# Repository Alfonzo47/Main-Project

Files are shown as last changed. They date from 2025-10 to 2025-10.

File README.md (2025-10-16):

# Main-Project

# Project Ironman

This project focoses on developing a small prototype of an isokinetic dynamometer specifically designed for a single finger joint to facilitate the collection of relevant data 
and validate the practical functionality of the design. The idea of our device is to measure muscle strength under a constant angular velocity or extension. The core goal of this
prototype is to strip down the functionality of the original, full-scale clinical isokinetic dynamometer to just a few essential components. This makes the device significantly 
cheaper and easier to implement in various smaller clinics or hospitals. Our intended user is primarily physiotherapists and researchers who require the data for the 
rehabilitation of patients with joint related injuries. Our project aims to widen the access to this type of machine.

# Components we used
- Steppermoter: Nema17
- Oled-Screen: 0.96 tum, I20
- Amplifyer: HX711
- Loadcell
- Driver: A4988
- Arduino microcontroller: r4 wifi
- Micro SD card
- Magnetic Encoder: AS5600

# Technical Approach

The system's core consists of an Arduino microcontroller integrated with an AS5600 magnetic encoder. The control logic is developed using the C language, ensuring quick execution 
for real-time control and analysis. The physical motion simulates finger flexion/extension using a specially 3D designed gear-driven system. A Load Cell is mounted on one of the 
gears, acting as the axis where the user's finger applies force during the simulated extesion.

The key to achieving Isokinetic Control is:
- Encoder Measurement: The AS5600 encoder continuously measures the angular position of the moter shaft.
- Software: It combines all the working components as well as documenting all the data in real time. Furthermore the software saves all the data, showing applied force at a
certain angle.  
- Data Collection: Simultaneously, the Load Cell accurately measures the applied force and the magnetic encoder helps to show at what angle the motor is in the rotation.

Both angle and weight values are updated and displayed in real time, while the code continuously drives the motor. The data is showed both on the OLED-screen during the trail and on a computer after the trail, making it possible to analyze and plot.

# User Interaction

The user interacts with the prototype through a simple and intuitive setup. The user places their finger on the load cell axis, where the mechanical system simulates controlled
finger extension. The prototype is supose to mimic the basic functionality of the real isokinetic dynamometer so during the trail the user experiences some recistance while 
extending the finger with the loadcell. During this process, the data from the loadcell and the magnetic encoder is transmitted to the software and visualized through a C-based interface and provides real-time readings of the angle and applied force during the test. The user experience is designed to be straightforward, allowing for easy setup and clear
feedback without the complexity of a full clinical device.

# Start up the Arduino-system

https://curiousscientist.tech/blog/as5600-magnetic-position-encoder

# Designs 





The figure shows a geardesign to combine the motor to the loadcell





The figure shows a piece to combine the magnetic encoder and the motor 





caseSketch

The figure shows the intended design for the prototype. This model offers the user to rest the palm while doing the test. The cylindrical shape in the design represents one of the gears



The figure shows the schematic for the electrical circuit made in KiCad





The figures shows the KiCad circuit on a PCB board and a 3D design of the PCB board to print for later use

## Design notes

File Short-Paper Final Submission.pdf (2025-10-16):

# Ironman

T.Thorisson, T.C.Linusson, S.Öberg. L.Birk. B.Chen

# Abstract

Isokinetic dynamometers are essential tools for measuring muscle strength, but their high cost and large size limit their use. By creating a more simplified and affordable version, accessibility will increase for clinics, leading to more data for researchers and improved patient rehabilitation.

# 1.1 Introduction

Isokinetic dynamometers are valuable tools in healthcare and sports medicine because they provide detailed information about dynamic muscle contractions [1]. However, commercial systems are typically large, expensive, and require professional operation, making them difficult to implement in smaller clinics or hospitals [2,3].

Traditional methods like manual and isometric testing cannot accurately capture strength changes during eccentric contractions or across full joint ranges of motion but isokinetic dynamometers address these issues [4]. However by simplifying the design, focusing only on angle and torque measurements, using compact components, a low-cost, motor-driven dynamometer with sensors and 3D modeling support could significantly reduce cost and size, making it more accessible for wider clinical use.

# 2.1 Design

A small-scale prototype of an isokinetic dynamometer used on the finger was constructed to facilitate the collection of relevant data and validate the practical functionality of the design. The system's motor is operated by a microcontroller (MCU) that uses sensors to control its operation via force and angle from an index finger extension.

### 2.2 Case Design

The prototype case was designed to house and protect the internal components of the isokinetic dynamometer, while ensuring ergonomic interaction for the user, consisting of three main sections, space for the motor, sensors and MCU. The upper section accommodates the motor and its attached gear as well as a magnetic sensor that’s attached to the motor. Below is additional space for a bottom gear where the load cell is attached to, forming an axis on which the user’s finger applies force to. Then there is more space in the section where the user’s palm will rest that contains most of the MCU and circuitry.

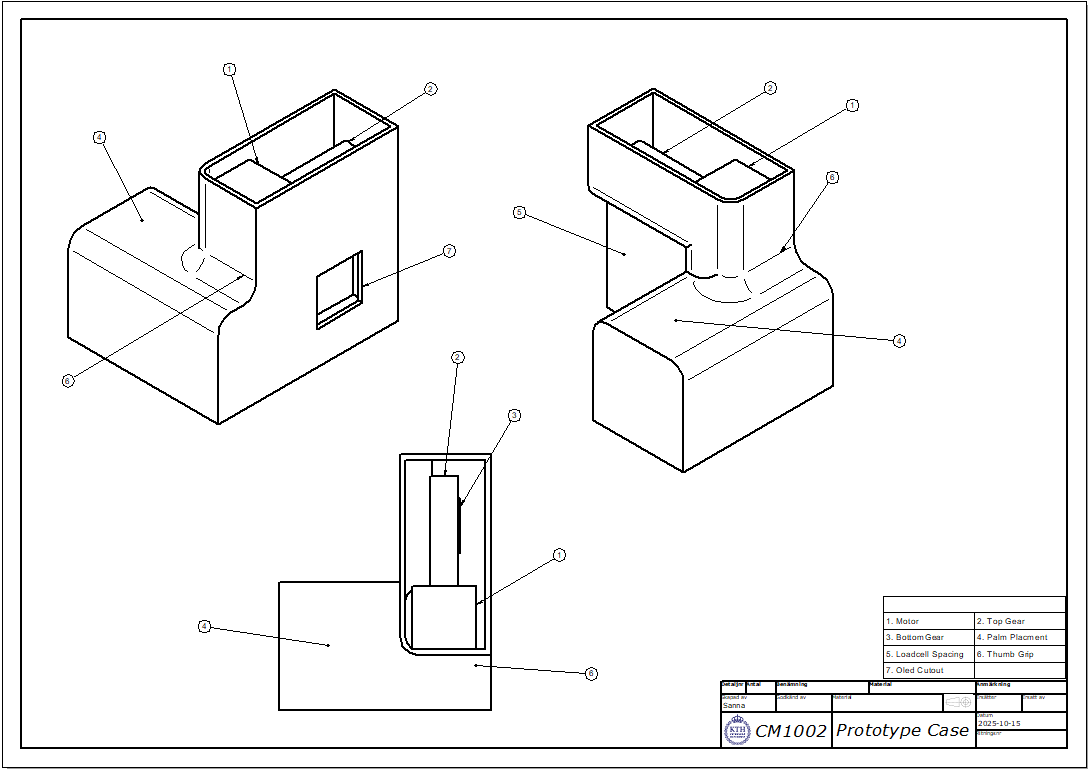
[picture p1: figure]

Figure 1 shows a CAD sketch on the intended vision for the final prototype. This sketch can be flipped for right hand usage.

### 2.3 Gear Design

A worm gear transmission structure can convert the sliding of two helical surfaces into rotation of different surfaces. This design uses this system as the power transmission structure of the dynamometer.

Design decisions were based on threads of ISO TR16×3 to ensure compatibility and 3D printing. To achieve reversible transmission and maintain high efficiency, the worm gear features 24 teeth, resulting in a 24:1 transmission ratio, balancing speed control with a compact design. The module is set at 1.0 mm, the pressure angle at 20°, and the center distance at approximately 20 mm.

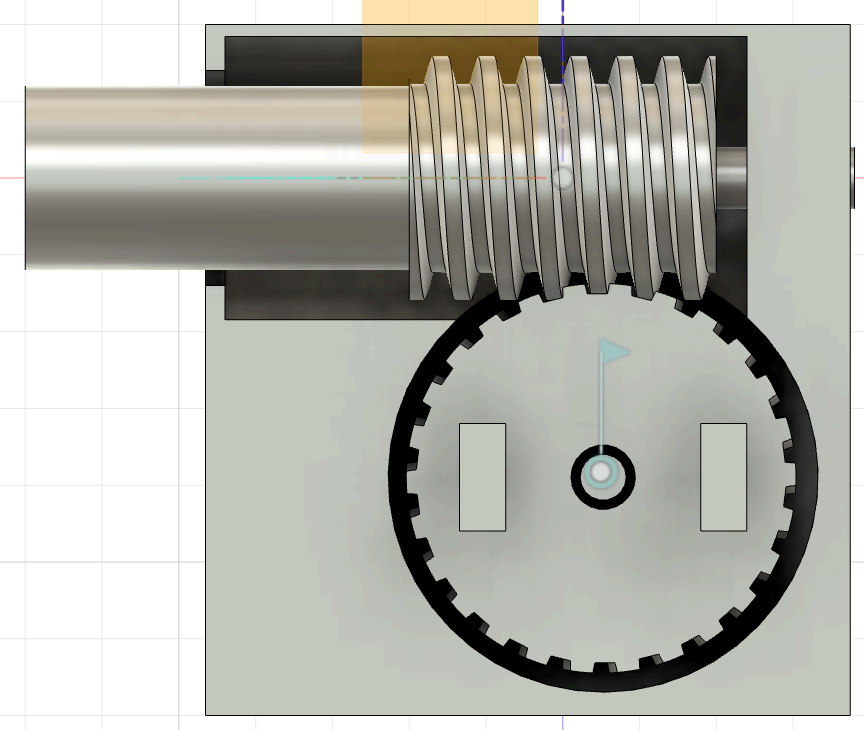
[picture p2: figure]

Figure 2 shows the worm drive in transmission structure

### 2.4 System Design

Electrical schematic are composted by the following components: Arduino UNO R4, HX711 amplifier, AS5600 magnetic encoder, micro SD card socket, 0.96” I2O oled-display, and A4988 motor driver, powering the stepper motor, all connections are shown in figure 3. Because AS5600, micro SD card socket, and HX711 have their own breakoutboards, they are connected externally with pinheaders, as well as the steppermotor. The complete HX711 circuit was added to the schematic for future compatibility. Furthermore, the A4988 gets its + 9 V (Volt) from an external power supply unit, which is only connected to the capacitor, demonstrated in figure 3. The remaining circuitry is only powered by the Arduino’s +5V and ground port, which is in turn powered by an USB-C port attached to the Arduino. Additionally, visual presentation of a potential PCB is illustrated in figure 4.

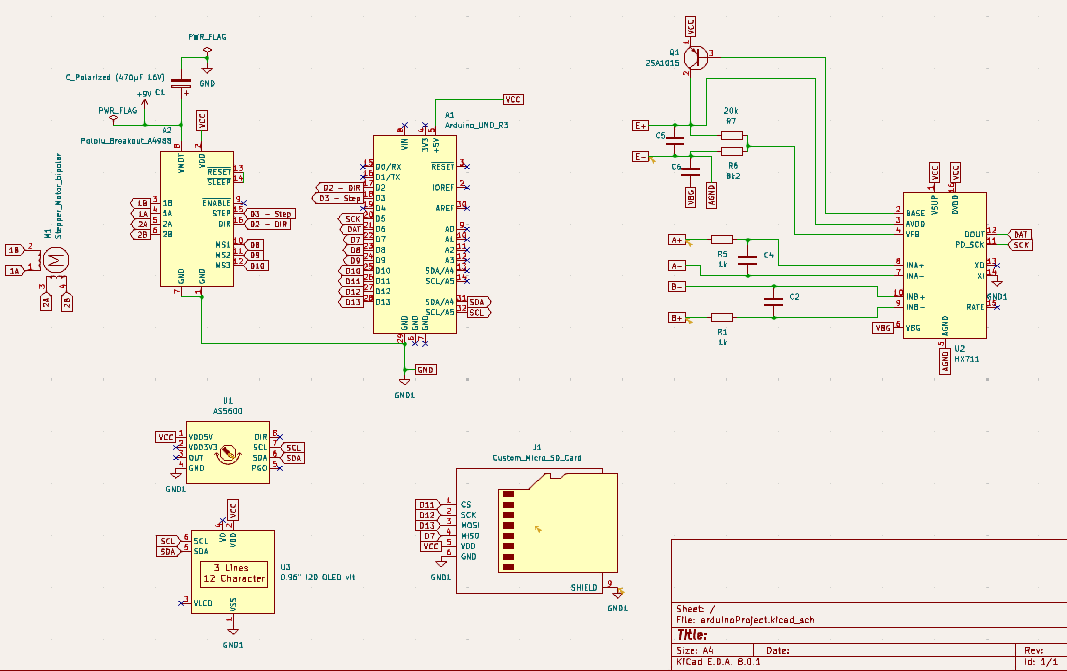
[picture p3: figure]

Figure 3 shows a KiCad schematic of the electrical design.

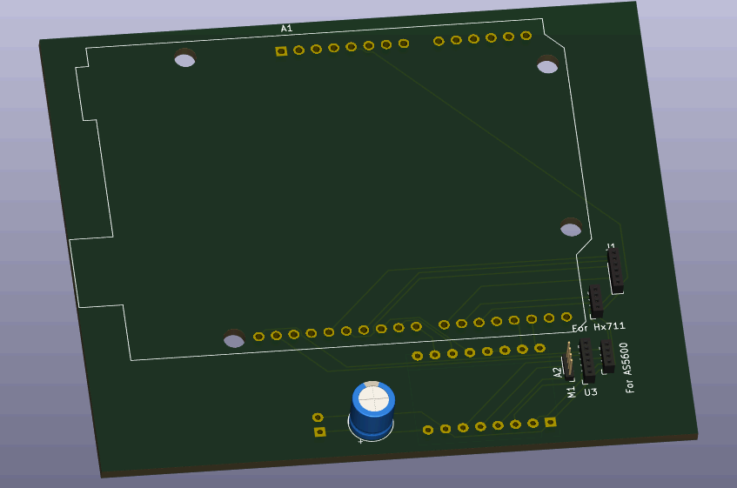
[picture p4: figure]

Figure 4 shows a visual representation of the potential PCB.

### 2.5 Software Design

The software combines all the working components as well as documenting all the data in real time. Furthermore the software saves all the data, showing applied force at a certain angle.

# 3.1 Results

The results show that the first prototype can measure the applied force as well as the corresponding angle which in turn was intended as shown in figure 5.

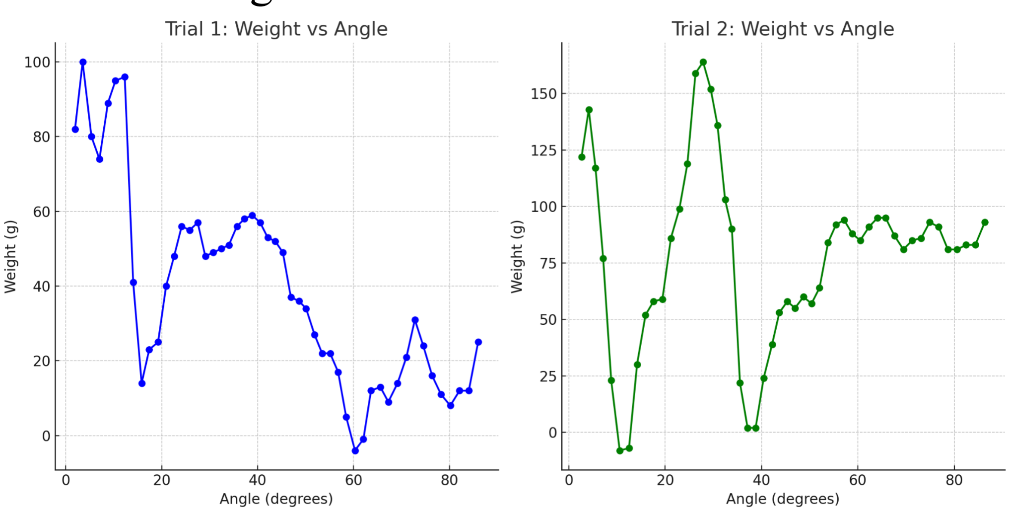
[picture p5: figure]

Figure 5 shows a graph of the applied force on depending on the angle of the sensor

# 4.1 Conclusion

In conclusion, isokinetic dynamometers are essential tools for measuring muscle strength, but their high cost and large size limit their use. The objective with this project was creating cheaper and simplified versions to implement in healthcare. The prototype was constructed to validate the practical functionality of the design by making a small-scale prototype for the finger. The system is operated by a microcontroller that uses sensors to control its operation via force and angle alongside a motor. Although, the prototype demonstrates that small, economical dynamometers are feasible and have potential for use in rehabilitation applications in the future. Whereas potential future work should implement a more structured and detailed planning approach, implementing a better gearbox and motor for increased torque.

# 5.1 Future Work

For future projects, the group would highly recommend adopting a more structured and detailed planning approach earlier in the process. The initial phase suffered from a slightly unclear project vision and a rush towards implementation and meeting deadlines. This resolved some stress at the end and making some emergency solutions on the prototype. Future ideas for improvements could be, implementing a planetary gear box for increased torque and helical gear to transport the movement to the gearbox. Together with a DC motor in order to have precise control and more force available. What’s the next step? Either continue adjusting and developing the current prototype or moving forward by making the next prototype. A bigger variant for the leg area, that will be more simplified, affordable, and has an increased accessibility for e.g., clinics. This is because the prototype demonstrates that the idea works and can be produced with further time.

# 6.1 References

[1] “Isokinetic dynamometry: implications for muscle testing and rehabilitation,” PubMed, 1986.
https://pubmed.ncbi.nlm.nih.gov/3525192/ (https://pubmed.ncbi.nlm.nih.gov/3525192/)
[2] M. Mendoza M., R. Miller RG, California Pacific Medical Center, and Elsevier Inc., “Muscle Strength, Assessment of,” Encyclopedia of the Neurological Sciences (Second Edition), 2014.
[3] R. Gülch, “Force-Velocity relations in human skeletal muscle,” International Journal of Sports Medicine, vol. 15, no. S 1, pp. S2–S10, Jan. 1994.
[4] A. Ivarsson and A. Cronström, “Agreement between isokinetic dynamometer and hand-held isometric dynamometer as measures to detect lower limb asymmetry in muscle torque after anterior cruciate ligament reconstruction,” International Journal of Sports Physical Therapy, vol. 17, no. 7, Nov. 2022.

# 7.1 Appendix

Github link:
https://github.com/Alfonzo47/Main-Project

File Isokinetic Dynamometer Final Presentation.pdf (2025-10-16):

# Isokinetic Dynamometer Ironman

### Ludwig Birk, Thrainn Thorisson, Boyang Chen, Timothy Linusson, Sanna Öberg

# Content

# •Introduction •Problem Statement •Technical Approach •User Interaction •Results •Methodology

# Introduction

- A small prototype
- Is the data somewhat relevant and practical
- Measure muscle strength for a continuous extension
- The goal with this project
- The intended user are hospitals and clinics

# Problem Statement

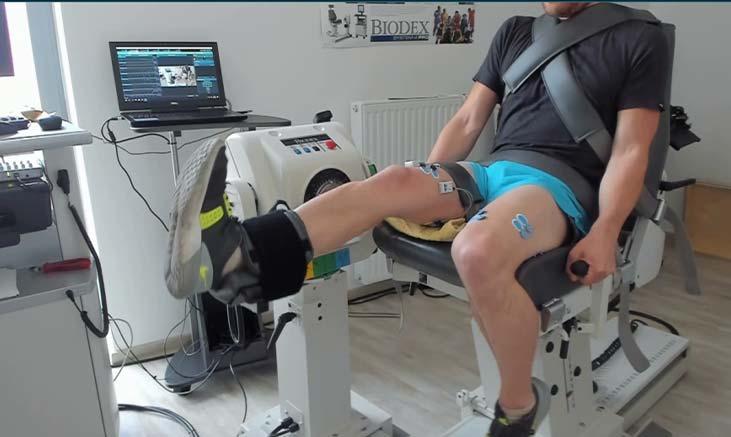
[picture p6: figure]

- Large and expensive
- Targeted area limitations
- Decreased Accessibility
- Limited Research
- Sub-Optimal Rehabilitation Outcomes

# Technical Approach

Sensors, Components and Software:

- Arduino microcontroller
- Open source
- Load cell (+Amplifier), Stepper motor (+driver), Magnetic Encoder, SD-card module
- Encoder is commonly used and accurate
- Coded in C
- Takes values from Load Cell and Encoder and saves data to SD-card
- 3D designed gear-driven system
- Mounted with a Load Cell
- OLED-display
- Displaying angles and force in real-time

Key features to achieving Isokinetic Control:

- Encoder Measurement
- Continuous measurement of angular position
- Software Implementation
- Tracks total rotation
- Updating measurements in real-time
- Data Collection
- Load Cell measuring applied force

# User Interaction

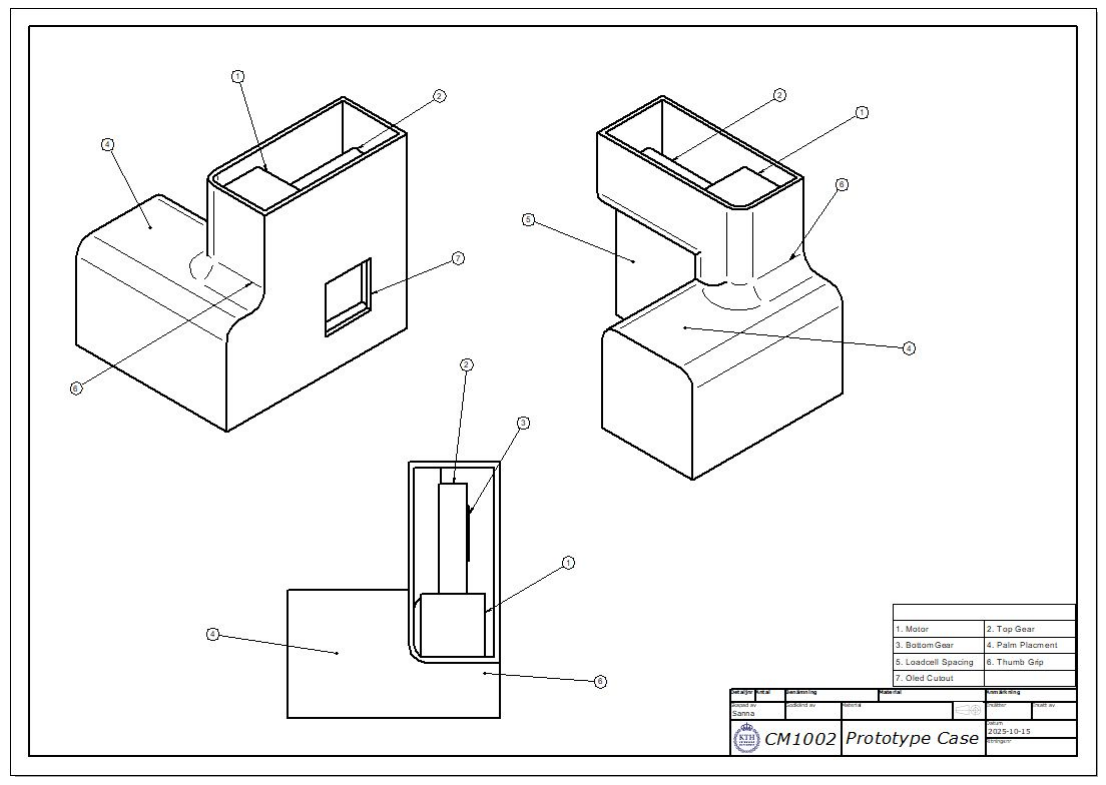
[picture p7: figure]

- Users finger is placed along the load cell
- Physical interaction with resistive motion
- Data is collected during process
- Straightforward user experience
- Easy setup
- Clear feedback
- No complexity
- More accessible in use and cost
- Rounded edges for ergonomic comfort

# Results

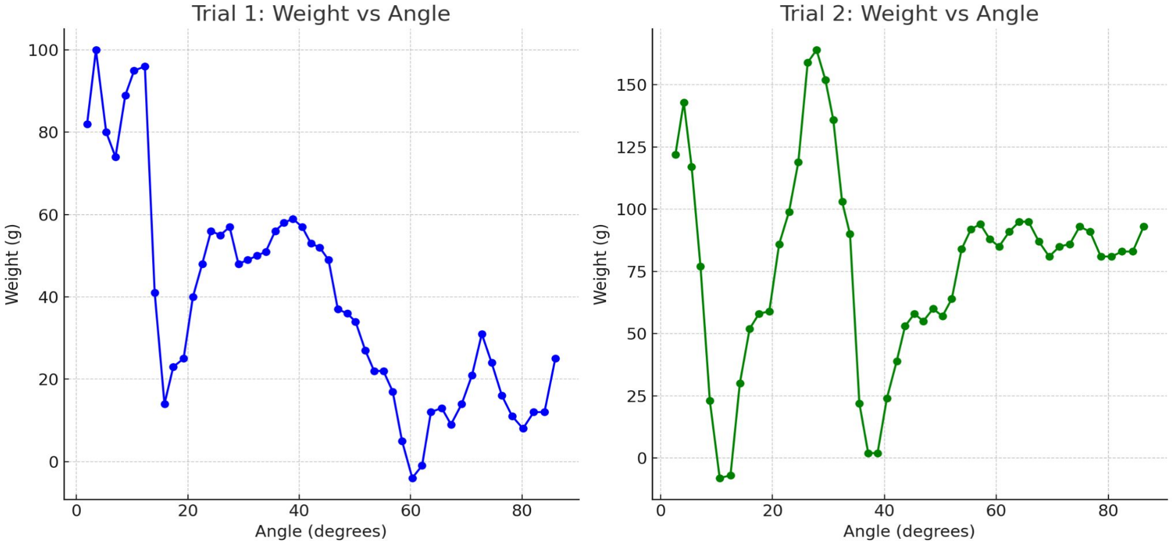
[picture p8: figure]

# Project Methodology

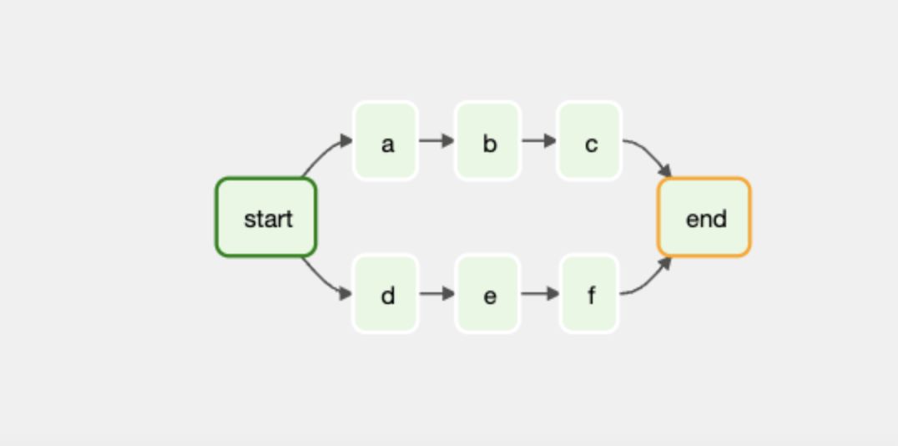
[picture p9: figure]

Parallel and Modular design methodology(GitHub Projects)

- Mechanical structure
- Electronic control
- Software design

To Improve

- Structured and detailed planning approach
- Deeper preliminary research
- time-efficient solution

# Thank you for listening!

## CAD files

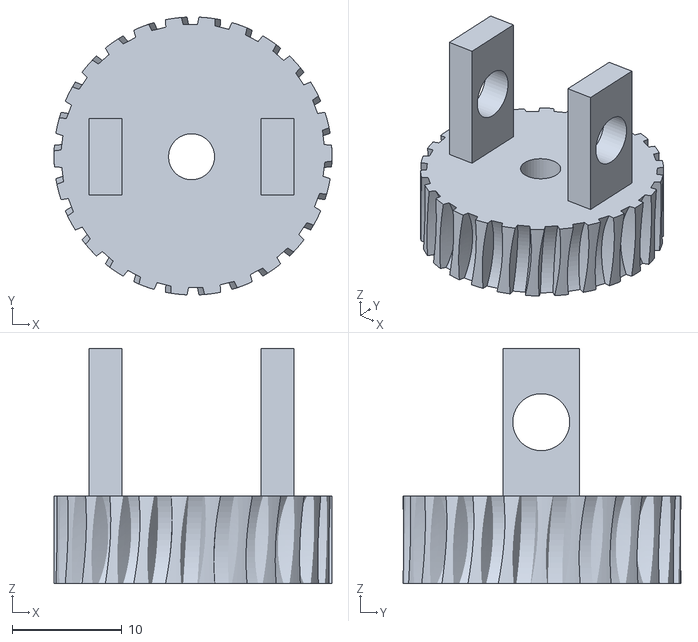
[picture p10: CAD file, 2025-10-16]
gear.stl
25.4 x 25.4 x 21.5

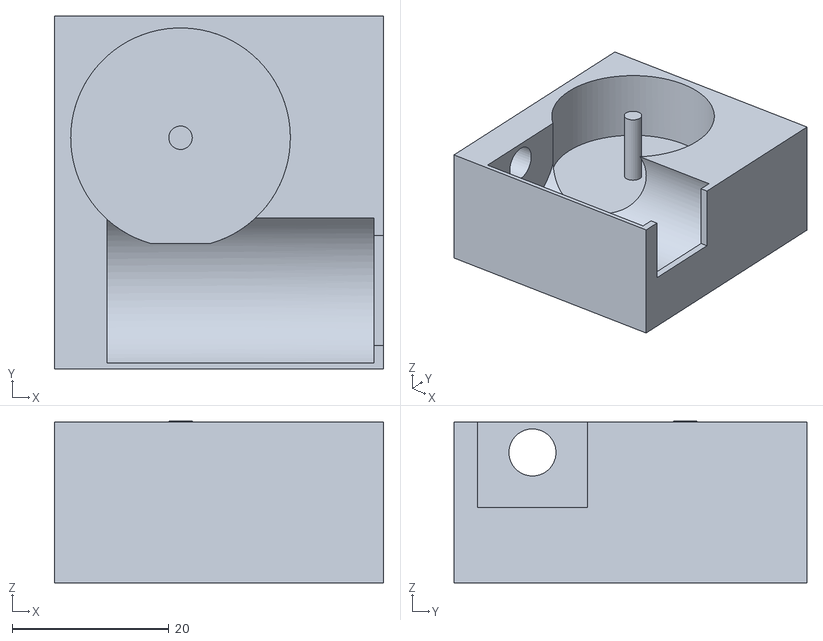
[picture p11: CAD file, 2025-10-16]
the case.stl
42.0 x 45.0 x 20.6

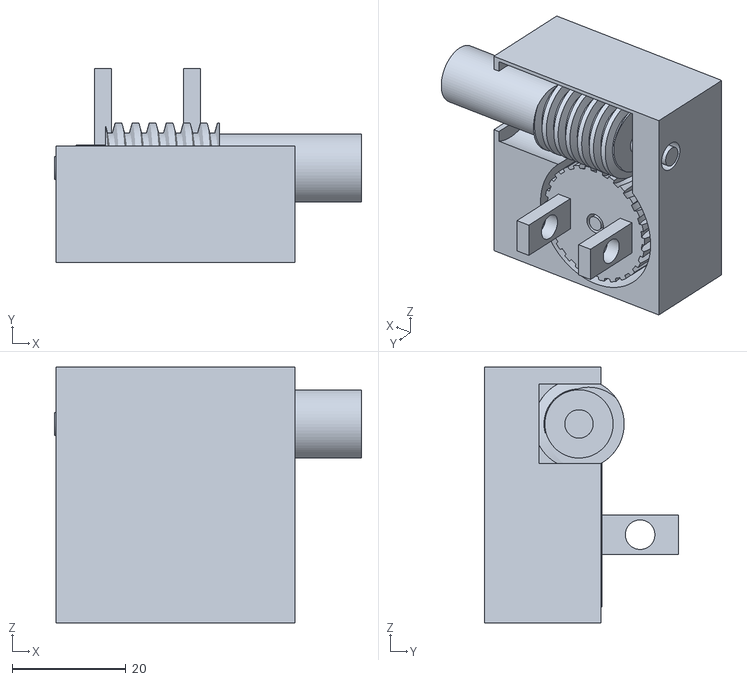
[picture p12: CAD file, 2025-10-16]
worm drive.stl
54.0 x 34.1 x 45.0

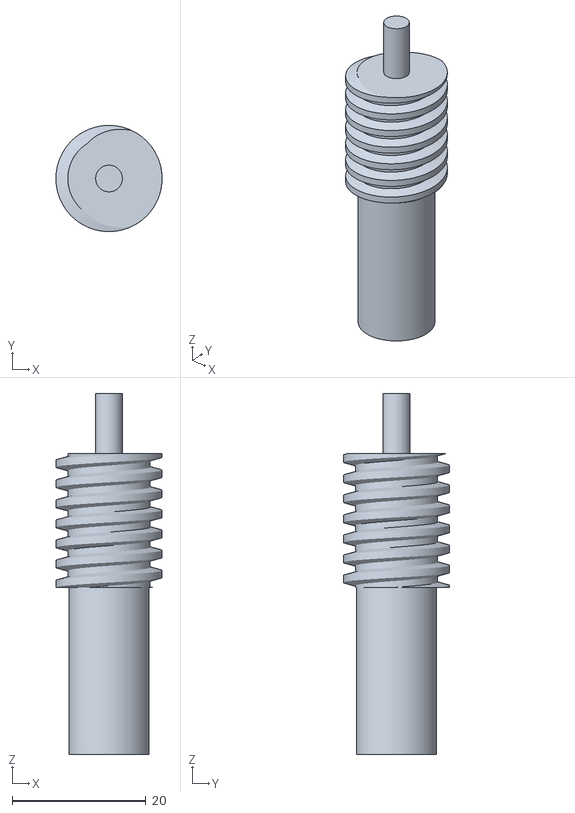
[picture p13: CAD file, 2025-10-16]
worm.stl
15.9 x 15.9 x 54.0

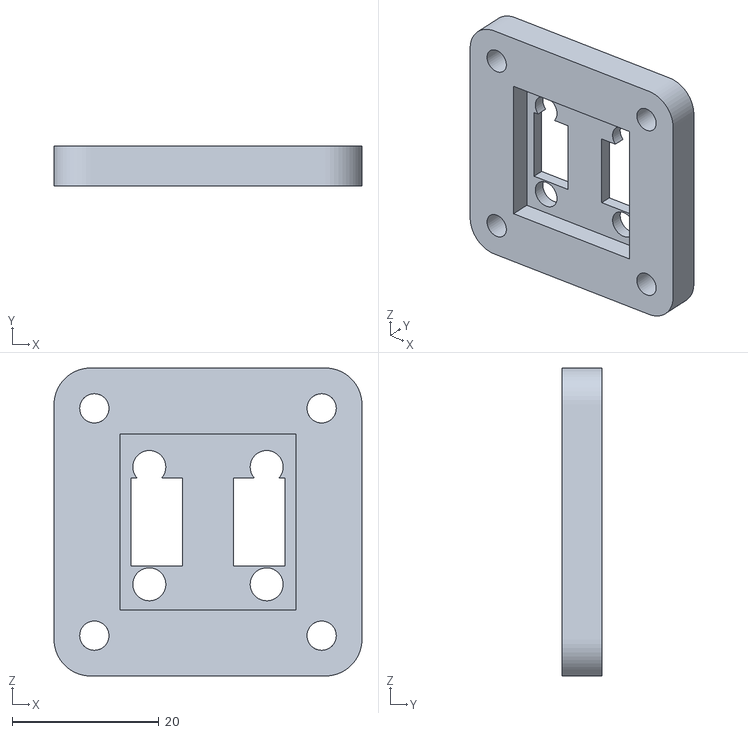
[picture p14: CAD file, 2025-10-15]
AS5600Mount_nema17.stl
42.0 x 5.50 x 42.0

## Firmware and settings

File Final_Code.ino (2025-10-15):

//AS5600 coding is based on https://curiousscientist.tech/blog/as5600-magnetic-position-encoder and the Arduino 5600 library
//Loadcell Code is inspired by https://randomnerdtutorials.com/arduino-load-cell-hx711/
//SD-card reader is based on The official Arduino Library

#include <Wire.h> 
#include <Adafruit_GFX.h>
#include <Adafruit_SSD1306.h>
#include "HX711.h"
#include <SD.h>

// HX711
#define LOADCELL_PIN1 5
#define LOADCELL_PIN2 6
HX711 scale;
int readweight;
int lastread;
#define CALIBRATION_FACTOR -400

#define SCREEN_WIDTH 128 // OLED display width, in pixels
#define SCREEN_HEIGHT 64 // OLED display height, in pixels

#define stepPin 3 
#define dirPin 2
#define MS1 9
#define MS2 8
#define MS3 7

#define BUTTON_PIN 4 //Extra Tare Function
#define FULLROTATION 200
#define FULLROTQUARTER 800

// Declaration of OLED
#define OLED_RESET     -1 // Reset pin # (or -1 if sharing Arduino reset pin)
Adafruit_SSD1306 display(SCREEN_WIDTH, SCREEN_HEIGHT, &Wire, OLED_RESET);


//AS5600
int magnetStatus = 0; 
int lowbyte; //raw angle 7:0
word highbyte; //raw angle 7:0 and 11:8
int rawAngle; //final raw angle 
float degAngle; //raw angle in degrees (360/4096 * [value between 0-4095])
int quadrantNumber, previousquadrantNumber; //quadrant IDs
float numberofTurns = 0; //number of turns
float correctedAngle = 0; //tared angle - based on the startup value
float startAngle = 0; //starting angle
float totalAngle = 0; //total absolute angular displacement
float previoustotalAngle = 0; 
//

//Library
#define VALUESIZE 1000 //Store values for 20 unique isokinetic tests
#define WEIGHTANGLE 3 //Store weight + angle
#define chipSelect 10 //Where the SD-card module communicates from
File myFile;
float lib[VALUESIZE][WEIGHTANGLE];

void setup()
{
  Serial.begin(115200); //start serial - tip: don't use serial if you don't need it (speed considerations)
  Wire.begin(); //start i2C  
	Wire.setClock(800000L); //fast clock

  pinMode(stepPin,OUTPUT); 
  pinMode(dirPin,OUTPUT);
  pinMode(MS1, OUTPUT);
  pinMode(MS2, OUTPUT);
  pinMode(MS3, OUTPUT);
  digitalWrite(dirPin,HIGH); //Set inital rotation

  digitalWrite(MS1, LOW);
  digitalWrite(MS2, LOW);
  digitalWrite(MS3, LOW); //LOW-HIGH-LOW: Quarter step mode!
 
  checkMagnetPresence(); //check the magnet (blocks until magnet is found)
  ReadRawAngle(); //make a reading so the degAngle gets updated
  startAngle = degAngle; //update startAngle with degAngle - for taring

  //------------------------------------------------------------------------------
  //OLED part
    if(!display.begin(SSD1306_SWITCHCAPVCC, 0x3C)) { 
    Serial.println(F("SSD1306 allocation failed"));}
    
  delay(1000);
  display.clearDisplay();
  display.setTextSize(2);
  display.setTextColor(WHITE);
  display.setCursor(0, 0);
  display.println("Welcome...");
  display.display();
  //delay(2000);

  Serial.println("Starting load cell...");
  scale.begin(LOADCELL_PIN1, LOADCELL_PIN2);

  scale.set_scale(CALIBRATION_FACTOR);   // this value is obtained by calibrating the scale with known weights
  scale.tare();               // reset the scale to 0

  ////// SD-CARD PART
    Serial.print("Initializing SD card...");

  if (!SD.begin(chipSelect)) {
    Serial.println("initialization failed!");
  }
 
  SD.remove("test2.txt"); //Remove previous file/values. Remove this line if you want to keep previous values
  myFile = SD.open("test2.txt", FILE_WRITE);
    if (myFile) {
    Serial.print("Writing to test2.txt...");
    myFile.println("Weight (g), Angle (degrees)"); // Write the header
    myFile.close();
    Serial.println("Writing header...");
  } else {
    Serial.println("Error opening test2.txt");   // if the file didn't open, print an error:
  }
}

void loop()
{    
    ReadRawAngle(); //ask the value from the sensor
    correctAngle(); //tare the value
    checkQuadrant(); //check quadrant, check rotations, check absolute angular position
    loadcell(); //Weight
    refreshDisplay(); //Show Angle and Weight on the OLED
    checkforce(); //Check if enough force has been applied to start the system
}

void motor() { //Test function for motor
  digitalWrite(dirPin, HIGH);
    for(int x = 0; x < (FULLROTATION/4); x++) { 
    digitalWrite(stepPin,HIGH); 
    delayMicroseconds(500); 
    digitalWrite(stepPin,LOW); 
    delayMicroseconds(500);  
    }
    //delay(1000);
}

void motor_goin90() //Turn 90 degrees while measuring force/angle and writing to library
{
  digitalWrite(dirPin, HIGH);
    for(int x = 0; x < (FULLROTATION/4); x++) { 
    digitalWrite(stepPin,HIGH); 
    delayMicroseconds(50000); 
    digitalWrite(stepPin,LOW); 
    delayMicroseconds(50000);  

    ReadRawAngle(); 
    correctAngle(); 
    checkQuadrant(); 
    loadcell();
    refreshDisplay();

    lib[x][0] = readweight;
    lib[x][1] = totalAngle;
    }

    delay(1500);
    warningretract(); //Warn user to remove finger from device
    writetofile(); //Write library values to file
    delay(1500);

    digitalWrite(dirPin, LOW); //Turn back to original position
    for(int x = 0; x < (FULLROTATION/4); x++) { 
    digitalWrite(stepPin,HIGH); 
    delayMicroseconds(10000); 
    digitalWrite(stepPin,LOW); 
    delayMicroseconds(10000);  
    ReadRawAngle(); 
    correctAngle(); 
    checkQuadrant(); 
    }
}

void ReadRawAngle()
{ 
  //7:0 - bits
  Wire.beginTransmission(0x36); //connect to the sensor
  Wire.write(0x0D); //figure 21 - register map: Raw angle (7:0)
  Wire.endTransmission(); //end transmission
  Wire.requestFrom(0x36, 1); //request from the sensor
  
  while(Wire.available() == 0); //wait until it becomes available 
  lowbyte = Wire.read(); //Reading the data after the request
 
  //11:8 - 4 bits
  Wire.beginTransmission(0x36);
  Wire.write(0x0C); //figure 21 - register map: Raw angle (11:8)
  Wire.endTransmission();
  Wire.requestFrom(0x36, 1);
  
  while(Wire.available() == 0);  
  highbyte = Wire.read();
  
  highbyte = highbyte << 8; //shifting to left
  rawAngle = highbyte | lowbyte; //int is 16 bits (as well as the word)
  degAngle = rawAngle * 0.087890625; //AS5600 accuracy of the model used
}

void correctAngle()
{
  correctedAngle = degAngle - startAngle; //this tares the position

  if(correctedAngle < 0) //if the calculated angle is negative, we need to "normalize" it
  {
  correctedAngle = correctedAngle + 360; //correction for negative numbers (i.e. -15 becomes +345)
  }
  else
  {
    //do nothing
  }
}

void checkQuadrant()
{
  //Quadrant 1
  if(correctedAngle >= 0 && correctedAngle <=90)
  {
    quadrantNumber = 1;
  }
  //Quadrant 2
  if(correctedAngle > 90 && correctedAngle <=180)
  {
    quadrantNumber = 2;
  }
  //Quadrant 3
  if(correctedAngle > 180 && correctedAngle <=270)
  {
    quadrantNumber = 3;
  }
  //Quadrant 4
  if(correctedAngle > 270 && correctedAngle <360)
  {
    quadrantNumber = 4;
  }
  if(quadrantNumber != previousquadrantNumber) //if we changed quadrant
  {
    if(quadrantNumber == 1 && previousquadrantNumber == 4)
    {
      numberofTurns++; // 4 --> 1 transition: CW rotation
    }

    if(quadrantNumber == 4 && previousquadrantNumber == 1)
    {
      numberofTurns--; // 1 --> 4 transition: CCW rotation
    }
    //this could be done between every quadrants so one can count every 1/4th of transition

    previousquadrantNumber = quadrantNumber;  //update to the current quadrant
  
  }  
  totalAngle = (numberofTurns*360) + correctedAngle; //number of turns (+/-) plus the actual angle within the 0-360 range
}

void checkMagnetPresence() //Only run during setup
{  
  //This function runs in the setup() and it locks the MCU until the magnet is not positioned properly
  Serial.print("Checking magnet presence...");

  while((magnetStatus & 32) != 32) //while the magnet is not adjusted to the proper distance - 32: MD = 1
  {
    magnetStatus = 0; //reset reading
    Serial.println("Magnet found!");

    Wire.beginTransmission(0x36); //connect to the sensor
    Wire.write(0x0B); //figure 21 - register map: Status: MD ML MH
    Wire.endTransmission(); //end transmission
    Wire.requestFrom(0x36, 1); //request from the sensor

    while(Wire.available() == 0); //wait until it becomes available 
    magnetStatus = Wire.read(); //Reading the data after the request   
  }      
}

void refreshDisplay()
{
  //Serial.print("Display refreshed...");
  //Serial.println(totalAngle);
  //float anglediff = 0;
  //anglediff = abs(totalAngle-previoustotalAngle);
    display.clearDisplay();
    display.setTextSize(1);
    display.setTextColor(WHITE);
    display.setCursor(0, 30);
    display.println("Weight:");
    display.setCursor(0, 40);
    display.setTextSize(2);
    display.print(readweight);

    display.setTextSize(1);
    display.setTextColor(WHITE);
    display.setCursor(0, 0);
    display.println("totalAngle:");
    display.setCursor(0, 10);
    display.setTextSize(2);
    display.print(totalAngle);
    display.display();  
    
    previoustotalAngle = totalAngle; //update the previous value	
}

void loadcell()
{
  int button = 0;
  button = digitalRead(BUTTON_PIN);
  //int weightdiff = 0;
  
  if (button == 1){ //In case of load cell problems, reset the scale
    Serial.print("Scale tare...");
    scale.tare();
  }
    readweight = round(scale.get_units());
    //weightdiff = abs(readweight - lastread);
    lastread = readweight;
}

void checkforce()
{
  //readweight = round(scale.get_units());
  if ((round(scale.get_units())) > 50){ //Motor starts when it detects a weight of 100 grams or more
      Serial.println("Weight detected");
      motor_goin90();
    }
}

void warningretract()
{
   display.clearDisplay();
   display.setTextSize(2);
   display.setTextColor(WHITE);
   display.setCursor(0, 0);
   display.println("Warning!");
   display.setCursor(0, 30);
   display.println("Retract!");
   display.display();
}

void writetofile()
{
  myFile = SD.open("test2.txt", FILE_WRITE);
  if (myFile) {
    for (int n; n < (FULLROTATION/4); n++) //Write to file and save
    {
    myFile.print(lib[n][0]);
    myFile.print("      ");
    myFile.println(lib[n][1]);
    }
    // close the file:
    myFile.close();
    Serial.println("done.");
  } else {
    // if the file didn't open, print an error:
    Serial.println("error opening test2.txt (writetofile function failed)");
  }
}

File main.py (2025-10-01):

from machine import Pin, PWM, ADC
import time
from as5600 import AS5600

# --- Configuration ---
adcpin = 28  # ADC pin connected to the potentiometer
pot = ADC(adcpin)

I2C_BUS_ID = 0
I2C_SDA_PIN = 4
I2C_SCL_PIN = 5
I2C_FREQ = 400000
DATA_FILE = "angle_data.txt"
LED_PIN = 25  # Onboard LED pin for Raspberry Pi Pico

# Function to save data
def save_data(angle_data, filename=DATA_FILE):
    """
    Appends the angle data to a specified file.

    Parameters:
    angle_data (float): The angle data to save.
    filename (str): The name of the file to save the data to.
    """
    try:
        with open(filename, "a") as file:
            file.write(f"{angle_data}\n")
        print(f"Data saved: {angle_data} to {filename}")
    except Exception as e:
        print(f"Error saving data: {e}")

# Function to extract saved data
def extract_data(filename=DATA_FILE):
    """
    Reads and returns the saved angle data from the specified file.

    Parameters:
    filename (str): The name of the file to read the data from.

    Returns:
    list: A list of saved angle data as floats.
    """
    try:
        with open(filename, "r") as file:
            data = [float(line.strip()) for line in file.readlines()]
        print(f"Data extracted from {filename}: {data}")
        return data
    except Exception as e:
        print(f"Error extracting data: {e}")
        return []

# Temporary function to clear the data file
def clear_data(filename=DATA_FILE):
    """
    Clears all data in the specified file.

    Parameters:
    filename (str): The name of the file to clear.
    """
    try:
        with open(filename, "w") as file:
            file.write("")  # Overwrite the file with an empty string
        print(f"Data cleared from {filename}")
    except Exception as e:
        print(f"Error clearing data: {e}")

def setup_pwm_output(pin_number, frequency=1000, duty_cycle=50):
    """
    Configures a GPIO pin to output a PWM signal.

    Parameters:
    pin_number (int): The GPIO pin number to use for PWM output.
    frequency (int): The frequency of the PWM signal in Hz (default: 1000 Hz).
    duty_cycle (int): The duty cycle of the PWM signal as a percentage (0-100, default: 50%).

    Returns:
    PWM: The configured PWM object.
    """
    try:
        pwm_pin = PWM(Pin(pin_number))  # Initialize the pin as a PWM pin
        pwm_pin.freq(frequency)  # Set the frequency
        pwm_pin.duty_u16(int((duty_cycle / 100) * 65535))  # Set the duty cycle (0-65535)
        print(f"PWM output configured on pin {pin_number} with frequency {frequency} Hz and duty cycle {duty_cycle}%.")
        return pwm_pin
    except Exception as e:
        print(f"Error setting up PWM output: {e}")
        return None

# Initialize I2C and AS5600
print("Initializing I2C...")
encoder = AS5600(I2C_BUS_ID, I2C_SDA_PIN, I2C_SCL_PIN, I2C_FREQ)
print("AS5600 initialized.")

led = Pin(LED_PIN, Pin.OUT)
led.on()  # Turn on the LED to indicate the program is running
print("LED is ON (Program is running).")

# Clear the data file (temporary usage)
clear_data()

# Main loop
try:
    while True:
        # Read the angle from the AS5600
        angle_in_degrees = encoder.read_angle()

        # Read the potentiometer value
        adc_value = pot.read_u16()  # Read ADC value (0–65535)
        voltage = (3.3 / 65535) * adc_value  # Convert to voltage
        print(f"Potentiometer Voltage: {voltage:.2f} V")
        
        duty_cycle1 = (adc_value / 65535) * 100  # Scale to 0–100%
        duty_cycle1 = round(duty_cycle1, 2)  # Round to 2 decimal places
        

        # Calculate the inverse duty cycle for the second PWM signal
        duty_cycle2 = 100 - duty_cycle1

        # Update the PWM signals' duty cycles
        pwm_signal1 = setup_pwm_output(pin_number=18, frequency=1000, duty_cycle=(int((duty_cycle1))) ) # Update duty cycle for PWM1
        pwm_signal2 = setup_pwm_output(pin_number=16, frequency=1000, duty_cycle=(int((duty_cycle2))) ) # Update duty cycle for PWM1
        print(f"Potentiometer ADC Value: {adc_value}")

        if angle_in_degrees is not None:
            # Save the angle data
            save_data(angle_in_degrees)
           
            # Print the angle
            print(f"Angle: {angle_in_degrees:.2f}")
        else:
            print("Error reading angle.")

        # Wait before the next reading
        time.sleep(1)  # Short delay for smoother updates
except KeyboardInterrupt:
    print("Program stopped. Extracting saved data...")
 
    # Turn off the LED when the program stops
    led.off()
    print("LED is OFF (Program stopped).")

    # Deinitialize the PWM signals
    if pwm_signal1:
        pwm_signal1.deinit()
    if pwm_signal2:
        pwm_signal2.deinit()

    # Extract and print saved data when the program is stopped
    saved_data = extract_data()
    print("Saved Data:", saved_data)

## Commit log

2025-09-27 Raspberry pi pico + AS5600
    Pico that reads angle and controls a motor with PWM signals
2025-10-15 Add files via upload
    This is a 3D printed piece to combine the motor and the magnetic encoder
    [AS5600Mount_nema17.stl]
2025-10-15 Update and rename as5600.py to as5600(old).py
    this code is no longer in use
    [as5600(old).py]
2025-10-15 Update and rename main.py to main(old).py
    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
    [main(old).py]
2025-10-15 added additional case sketch to README.md
2025-10-15 Add files via upload
    Code for the Arduino, Magnetic Encoder and the SD-card
2025-10-16 Add files via upload
    The gear system for the motor and the load cell
    [worm drive.f3d]
2025-10-16 Case sketch
    Just a visual representation of the prototype case, The motor and gears in the sketch have to be removed for printing as they are just for showing where they would sitt in the case. Measurments also 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
2025-10-16 test
    test to see if it works
    [gear.stl]
2025-10-16 Explanation of the circuit
    This is a video of us explaining the circuit
2025-10-16 Proof of concept
    This is a proof of concept for the first prototype
2025-10-16 KiCad file
2025-10-16 Add files via upload
    Here are all of our CAD files: gear, worm, the case and a file containing all parts
    [gear.stl, the case.stl, worm drive.stl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]
